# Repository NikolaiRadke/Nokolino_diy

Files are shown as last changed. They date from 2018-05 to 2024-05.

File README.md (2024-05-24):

Nokolino
  
The ATtiny-based litte brother of Noko. This is the Repository for the **diy - Do It Yourself** version. Tiny and cute. And everyone is invited to **contribute**. Nokolino is for everyone. Are you looking for the new PCB version? Look here: [Nokolino_pcb](https://github.com/NikolaiRadke/Nokolino_pcb), or are you an owner of a kit? Look [here](http://github.com/NikolaiRadke/Nokolino).  
  
What's new? See the [newsblog](https://github.com/NikolaiRadke/Nokolino_diy/tree/master/NEWS.md).   
  
Three Nokolinos
  
Like his big brother **Noko**, the little Nokolino delights it's surroundings with cheeky comments. But unlike Noko he is more obstinate - no radio, no display, no frills. Instead of an Arduino he has a small **ATtiny** microcontroller, only an on-off switch and a big button. But he is small, can stay active for days and is, in contrast to his big brother, very easy to build.  
  
Another useful application option would be to use the hardware without the monster suit as a **music box** in an old used doll to bring it back to modern days, maybe with other sounds or songs.  

What does he to - technically? Whenever you press his button, he will laugh. And when he's just turned on, he says something random randomly every statistically 10 minutes. That's ist. Quiet a lot for a stuffed monster!  
  
**Nokolino** stands for **No**ra and Ni**ko**s monster - the appendix **lino** describes the small version.  
  
### Notes for non-German Nokolino makers  
  
Right now, the building wiki, the voice set and the manual are in German. I'll try to translate the wiki and the manual on day. Until then, feel free to ask me for translation, if you need help. **Contribute!** I need an English voice set and English text files. In addition, any other language is welcome, Nokolino is to be cosmopolitan!
  
### Prerequisites
  
Nokolino needs Arduino IDE 1.6.6 or newer (https://www.arduino.cc/en/Main/Software). Copy the folder `Nokolino_diy/src/Nokolino/` into your sketch folder and install ATtiny support. See [how to compile](https://github.com/NikolaiRadke/Nokolino_diy/tree/master/howto_compile) for further instructions. 
  
### Content

```
Nokolino_diy/
├── howto_compile/
|   Manual how compile the sketches in your Arduino IDE and precompiled sketched  
|   └── precompiled/
|       Precompiled hex files
|       ├── ATtiny45/
|       |   Version for the ATtiny45.
|       └── ATtiny85/
|           Version for the ATtiny85.
|
├── linux_uploader/
|   Tool for uploading MP3-files to the JQ6500.
|
├── manual/
|   Nokolino manual in PDF format and a template for a packaging design.
|   └── scribus/
|       Source documents for Scribus with all illustrations and fonts.
|
├── mp3/
|   Voice set for Nokolino/Nokolina in German. English needed? Contribute!
|   ├── female/
|   |   Female voice for Nokolina.
|   |   ├── mp3_16MBit/
|   |   |   Voice set for the 2MB-JQ6500.
|   |   └── mp3_32MBit/
|   |       Enhanced voice set for the 4MB-JQ6500. 
|   └── male/
|       Male voice for Nokolino.
|       ├── mp3_8MBit/
|       |   Low qualitiy files for the 1MB-JQ6500.
|       ├── mp3_16MBit/
|       |   Voice set for the 2MB-JQ6500.
|       └── mp3_32MBit/
|           Enhanched voice set for the 4MB-JQ6500.  
|
├── schematics/
|   The schematics for the Nokolino parts, the Nokolino sewing pattern and shopping list.
|   └── geda/
|       Source documents for gEDA.
|
└── src/
    ATtiny sketch
    └── Nokolino/
        One file, no libraries, no frills. Just Nokolino. 
```
### Let's get started!

Interested in Nokolino? Great! Let's start here: [German wiki](https://github.com/NikolaiRadke/Nokolino_diy/wiki).  
English wiki will follow. One day...

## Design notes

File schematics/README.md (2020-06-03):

# Schematics

### Technical schematics
* **Nokolino.png**:  
NOKOlino's main schematic. It was written with [gEDA](http://www.geda-project.org/).  
* **Nokolino_phototransistor.png**:  
Optional light sensor extension schematic.  

### Other manuals

* **Nokolino_Pattern.pdf**:
NOKOs sewing pattern. 
* **Nokolino_Einkaufsliste.pdf**:
Shopping list in German.

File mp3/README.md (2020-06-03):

# Voice set for Nokolino - German

There are five sets: Three **male** sets, one for the 16MBit = **2MByte** variant of the JQ6500, and one for the 8MBit = **1MByte** variant in lower quality and a 32MBit **4 MByte** variant with more sound files, for newer 32MBit-JQ6500 modules. The fourth set is a 32MBit **4 MByte** **female** variant, brand new for *Nokolina* and the last set ist the 16MBit **2 MByte** variant.    
  
Copy these mp3s on the JQ6500 module. Strictly observe the sequence!
021.mp3 must be copied as the 21st file. See the [Wiki](https://github.com/NikolaiRadke/Nokolino_diy/wiki/MP3s-aufspielen) for more detailed instructions.  
  
**Windows** users can use the (chinese) interface. See this [instructions](http://sparks.gogo.co.nz/jq6500/index.html), written by James Sleeman. **Linux** and **Mac** users should try the [uploading tool](https://github.com/NikolaiRadke/Nokolino_diy/tree/master/linux_uploader), written by Max Reinhard.  
    
 **16MBit:**  
  
| Number  | Assignment |
| ---|---:|
| 001-030 | Response to belly button |
| 031-079 | Time based events |
| 080 | BEEP battery warning |
  
 **32MBit:**  
  
| Number  | Assignment |
| ---|---:|
| 001-040 | Response to belly button |
| 041-163 | Time based events |
| 164 | BEEP battery warning |
  
The male voice has been spoken by my fellow actor [Carsten Caniglia](https://filmmakers.de/carsten-caniglia). Why? 
He has done a great job - moreover I don't want to listen to my own voice every day, especially when development takes more than a year! (Ian said I sound really weird in real life. Thanks, mate.). The female voice was spoken by my fellow actress [Norma Anthes](http://norma-anthes.de), thank you, lady!    

### Your own voice set  
  
You want to use your own files? No problem. Look into the sketch **Nokolino.ino**, set the definition **Set_own** and change the lines  
``` #define Button_event  0 ```  for the last voice file when the button is pressed and  
``` #define Time_event   0``` for the last voice file for the time based events.  
The *beep* for the battery warning should be the last file.  
  
Keep in your mind, that the device ist limited to **4Mbyte - 256kb**, **2MByte - 256kb** or **1MByte - 256kb**!

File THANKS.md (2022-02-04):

# Thanks

These people helped me bringing life to Nokolino:  
  
- **Hans Radke** - (my dad) hardware construction and a lot of soldering.
- **Regina Radke** - (my mom) monster suit hints.  
- **Nora Linder** - creating and sewing the monster suit and spellchecking.
- **Carsten Caniglia** - the male voice of Nokolino. Look at his [Homepage](https://neidig.org/carsten-caniglia/). 
- **Norma Anthes** - the female voice of Nokolina. Look at her [Homepage](http://norma-anthes.de).  
- **Helga Hansen** - from the Make Magazin for promoting Nokolino.  
- **Elisabeth Seidl** - Media design.  
  
Active supporters:  

- **"Brickhub"** - bugfixes.  
- **Horst Friedrich** - the phototransistor idea.  
- **Daniel Bachfeld** - the QI wireless charging idea.  
- **Thomas Stolt** - bugfixes and Nokolino_pcb.  
- **"Nickneck"** - translating the JQ6500 uploader.  
- **Reinhard Max** - for the upload and rescue tool.  
  
Used ressources:  

- **Arduino board and IDE** - [www.arduino.cc](http://www.arduino.cc)  
- **ATtiny core** - [David A. Mellis](https://github.com/damellis)  
- **JQ6500 uploader** - [Reinhard Max](http://chiselapp.com/user/rmax/repository/jq6500)  
- **Suit inspiration - Ninni** - [RevoluzZa Blog](http://blog.revoluzzza.com/2009/02/25/tutorial-hopw-to-sew-a-revoluzzzionary-monster-wie-man-ein-revoluzzzionares-monster-naht/)  
- **VCC measuring** - [Tim on mikrocontroller.net](https://www.mikrocontroller.net/topic/315667)

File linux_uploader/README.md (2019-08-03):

# Uploading files on the JQ6500 with Linux

It is quite easy with this command line tool, written by [Reinhard Max](https://chiselapp.com/user/rmax/repository/jq6500).  I added a precompiled version (64 Bit). It is free, but it is also *beerware*... ;-)  

1. Check, if ``` ./jq6500 ``` is running.  
2. If not, compile it by yourself, just by typing ``` make ```. 
3. Try again.
4. Connect your JQ6500 module to your system with a micro USB cable. 
5. Test your device by typing  ``` ./jq6500 -S ```. The tool will tell you the detected flash size.  
6. 32 MBit modules: Upload your files by typing ``` ./jq6500 -W ../mp3/male/mp3_32MBit/* ```(32 MBit male voice)  or ``` ./jq6500 -W ../mp3/female/mp3_32MBit/* ``` (32 MBit female voice).  
7. 16 MBit modules: Upload your files by typing ``` ./jq6500 -W ../mp3/male/mp3_16_MBit/* ```(16 MBit male voice)  or ``` ./jq6500 -W ../mp3/female/mp3_16MBit/* ``` (16 MBit female voice). 

If your MP3 files are in another directory, modify the last argument.  

## Repairing a JQ6500 without Windows software
  
Strangely, some modules come without the integrated Windows software. If you have a friend in need without Linux, the tool can fix the module.

1. Like above, check if the tool is running correctly.  
2. Connect your JQ6500 module to your system with a micro USB cable.  
3. Just type ``` ./jq6500 -X ```. 

That's it. You can now use your module with Windows.  
  
## Repairing a JQ6500 without Windows software without Linux
  
If you are a Windows user see my [JQ6500-rescue-tool](https://github.com/NikolaiRadke/JQ6500-rescue-tool) repository. There you find a quite simple way to fix your module.

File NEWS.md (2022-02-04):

# Newsblog

# 2020
  
* **10.07.2020** Tested new IDE 1.8.13. Works good.  
* **04.06.2020** New release **V1.2-030819**.  
* **03.06.2020** The repository got a small rework.  
* **09.03.2020** Tested IDE 1.8.12. Yeah, it's working, too.  
* **13.02.2020** Tested IDE 1.8.11. Again, it's working.  
  
# 2019  
  
* **26.09.2019** Tested IDE 1.8.10. Still working.  
* **27.08.2019** New linux upload and repair tool. The make command now works with Debian/Ubuntu/Mint.  
* **05.08.2019** New release **V1.1-030819**.  
* **03.08.2019** Firmware **2.1-030819**: With some small hardware additions Nokolino can get a new voice set via USB!  
* **14.04.2019** Testet IDE 1.8.9. with no problems found.  
* **15.01.2019** Firmware **2.0-150119**: Reworked volume control. Some modules have issues after sleep mode.  
* **15.01.2019** Testet IDE 1.8.8. Works well.  

## 2018  

* **19.10.2018** New Linux upload tool. You can upload an english interface by typing ./jq6500 -X   
* **26.09.2018** See Nokolino and me at Wissensnacht Ruhr Gelsenkirchen: 28.08.2018.  
* **25.09.2018** Firmware **2.0-250918**: Optional complaining when button is pressed while it is dark.
* **22.09.2018** Firmware **2.0-220918**:
  * Optional startup beep.  
  * Optional phototransistor feature.  
  * Improved volume handling, some modules need more startup time.  
* **03.09.2018** See Nokolino an me at the Maker Faire Hannover: 15.09.-16.09. HCC Hannover.  
* **29.06.2018** Firmware **1.0-290618**: Improved power saving when battery is low.  
* **16.06.2018** Updated the upload tool.  
* **24.05.2018** Firmware **1.0-240518**: New 16MBit voiceset support.  
* **23.05.2018** Better data compression for 16MBit voiceset. You get 10 more files!  
* **15.05.2018** Updated the upload tool for the JQ6500 mp3 module. Note that it now needs the **-W** parameter to write files.  
* **14.05.2018** See Noko, Nokolino and me at the Maker Faire Berlin: 25.10.2018-28.10.2018, FEZ!  
* **12.05.2018** The new [Nokolino_pcb repository](https://github.com/NikolaiRadke/Nokolino_pcb) ist finished. I will still provide support for the old version. Promised.  
* **11.05.2018** The new female voice set for Nokolina is finished.  
* **04.04.2018** My hoster was offline for more than two weeks. I moved to a new one. The graphics in the GitHub will be back soon. What a waste of time...  
* **16.03.2018** Finished a JQ6500 rescue tool! See [my new repository](https://github.com/NikolaiRadke/JQ6500-rescue-tool).  
* **12.03.2018** New Firmware **1.0-120318**: Nokolino is now talking constantly while button is pressed.  
* **08.03.2018** Fixed flash tool for 32MBit MP3 modules.  
* **22.03.2018** Nokolino appears in the german [Make Magazin](https://www.heise.de/select/make/2018/1/1519698748803933)!  
* **27.01.2018** New firmware **1.0-270118**:  
Enhancement: Using EEPROM.length() makes ATtiny selection obsolete.  
* **26.01.2018** New firmware **1.0-260118**:  
Bugfix: New voice set selection compiles without errors now.  
Enhancement: Easy PCD/Breadboard switching.  
* **13.01.2018** Firmware **1.0-130118** and the enhanced voice set files for the 32MBit-JQ6500 variant added.  
* **11.01.2018** **Hardware bug found**: The speaker is connected to *pin 16 and pin 15*, not *pin 16 and pin 14*.   
* **10.01.2018** Alas, another bug found. New firmware **1.0-100118**:
Bugfix: Custom voice set with own events is now working correctly.  
* **09.01.2018** New firmware **1.0-090118**:  
Bugfix: EEPROM seed cyle now runs without initial settings.  
* **08.01.2018** Nokolino appears on [Heise Newsticker](https://www.heise.de/make/meldung/Nokolino-die-Miniaturausgabe-von-MP3-Monster-Noko-3935030.html)!  
* **05.01.2018** New firmware **1.0-050118**:  
Bugfix: Last time event was unused.  
Enhancement: Easier optional voice set replacement.
* **04.01.2018** Bugfixing day.  
* **03.01.2018** Finished the Wiki - Nokolino is ready for the world with release **V1.0-030118**.   
* **02.01.2018** Finished the GitHub. Now the Wiki will be completed.  
* **01.01.2018** Happy new year! I finished the sewing pattern this (tired) day.  
  
## 2017
* **31.12.2017** Created this file. Nokolino is ready to release! Wait! Not now, it is party time :-)  
The hardware is finished and the firmware **1.0-250517** is working great.

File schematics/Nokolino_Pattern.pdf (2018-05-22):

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

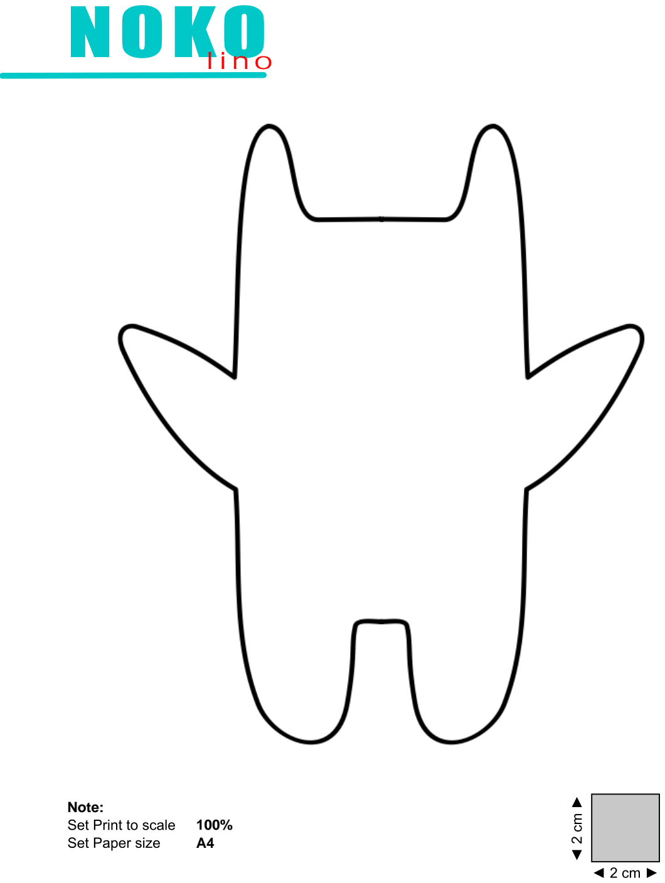
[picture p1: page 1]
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

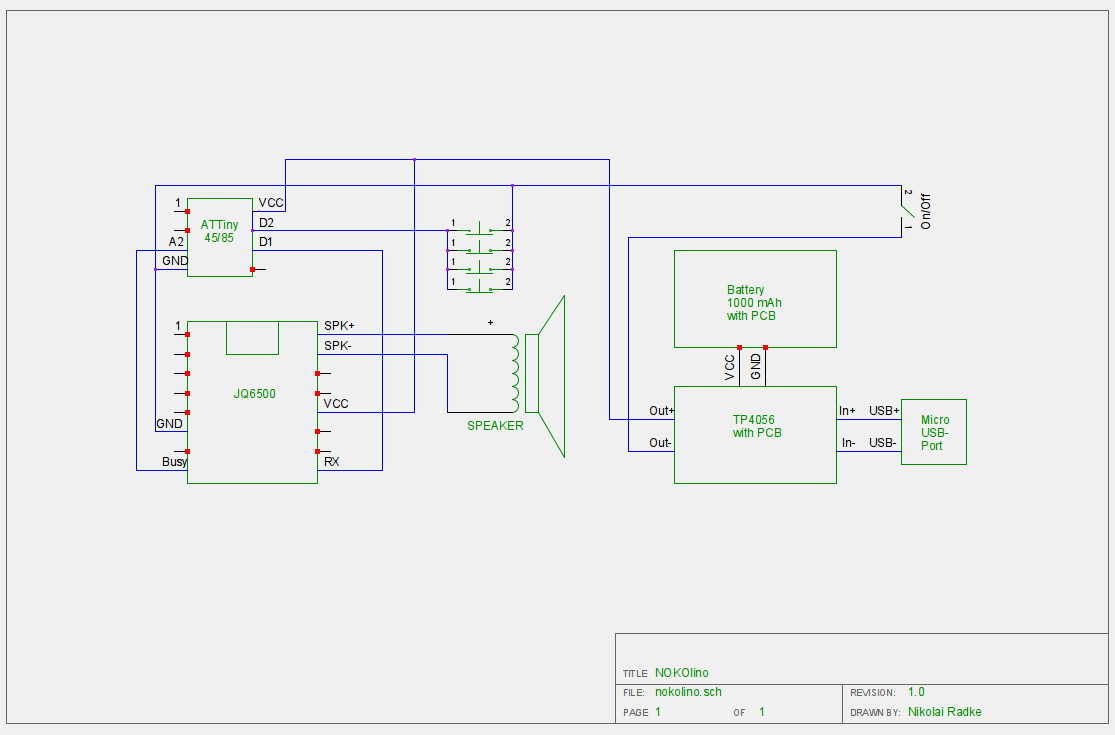
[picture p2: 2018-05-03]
schematics/Nokolino.png

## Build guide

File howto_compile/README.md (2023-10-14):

# Compiling instructions for Nokolino

In order to flash your ATtiny with the Nokolino-sketch, you need the **Arduino-IDE** (1.6.6 or higher), with installed **ATtiny-support** and an **Arduino** connected to your microcontroller.

### Preparing the IDE  
 
1. Open ``` File > Preferences ```.  
2. Find the field ``` Additional Boards Manager URLs ```.  
3. Enter ``` https://raw.githubusercontent.com/damellis/attiny/ide-1.6.x-boards-manager/package_damellis_attiny_index.json ```.  
4. Press ``` OK ```.  
5. Open ``` Tools > Board > Boards Manager ```.  
6. Select ``` attiny by David A. Mellis ```.  
7. Press ``` Install ```.

### Peparing your Arduino  

1. Connect your Arduino to your system.  
2. Open ``` File > Examples > ArduinoISP > ArduinoISP ```.  
3. Upload the sketch.

### Connecting your ATtiny with the Arduino  

1. Disconnect your Arduino.
2. Connect your ATtiny as seen below.
3. Add the 10uF capacitor.      
  
ATTINY-ARDUINO  
  
### Burning an Attiny bootloader  

1. Connect your Arduino to your system again.  
2. Select ``` Tools > Programmer > Arduino as ISP ```.  
3. Select ``` Tools > Board > ATtiny25/45/85 ```.  
4. Select ``` Tools > Processor > ATtiny85 ``` or ``` Tools > Processor > ATtiny45 ```.  
5. Select ``` Tools > Clock > 8 MHz (internal) ```.  
6. Start burning process with ``` Tools > Burn Bootloader ```.  

Now you can flash your ATtiny with any sketch you want! But this time, we focus on Nokolino.  

### Configuring Nokolino.ino

1. Set the avarage talking interval in line 31 (10 for 10 minutes is preset).  
. Set the volume in line 32. 25 is recommended for Nokolino, 22 for Nokolina.  
3. Are you building Nokolino on a breadboard? Set line 35.  
4. Select your voice set in line 38, 39 or 40  
5. If you don't want any battery warnings, comment out line 64.  
6. If you want Nokolino to be quiet on startup, comment out line 66.  
7. Check line 65 if you are using the optional light sensor.  

### Flashing Nokolino firmware
  
1. Open sketch **Nokolino.ino**.  
2. Upload the sketch.  
3. DONE.  

Now you can remove the microcontroller. You should keep the wiring alive to easly make some changes in the firmware.

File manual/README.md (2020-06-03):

# Manual for Nokolino
This folder contains the 6 page manual as a PDF, written in German. 
  
It has been written with [Scribus](http://www.scribus.net). The source files, fonts and illustrations are
in the folder [/scribus](https://github.com/NikolaiRadke/Nokolino_diy/tree/master/manual/scribus), so you can change 
the manual as you wish or translate it in any language. Please fork this repository or send a copy.

The other "2in1"-file is intended for printing a smaller manual with two pages on one. Choose duplex, 2 Pages on one and short edge.

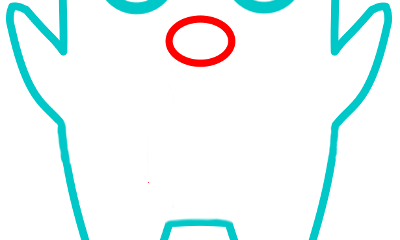
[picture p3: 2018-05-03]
manual/scribus/nokolino_bauch.png

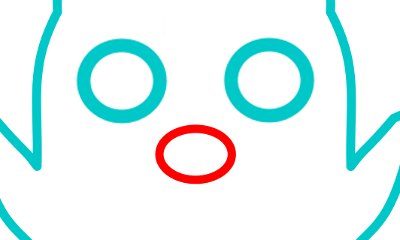
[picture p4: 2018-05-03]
manual/scribus/nokolino_lautsprecher.png

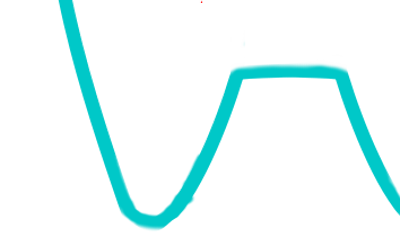
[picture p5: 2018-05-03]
manual/scribus/nokolino_usb.png

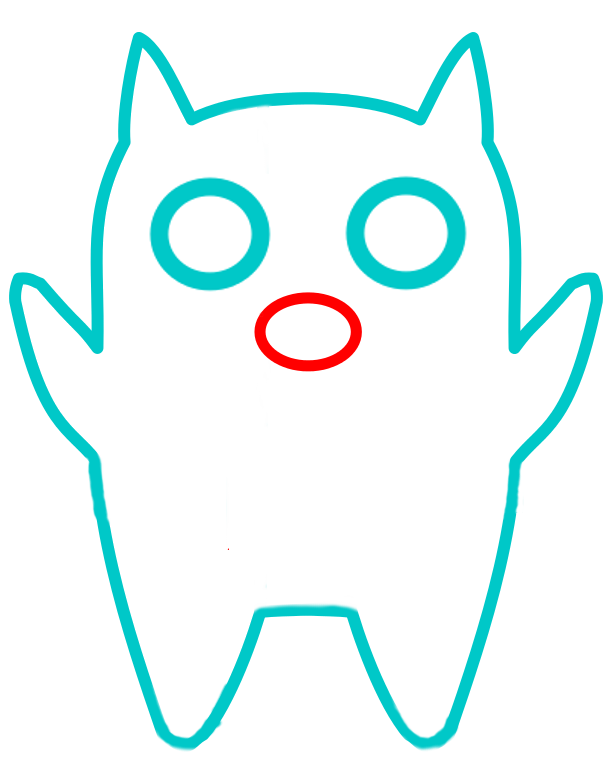
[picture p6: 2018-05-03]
manual/scribus/nokolino.png

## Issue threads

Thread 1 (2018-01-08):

Was macht der genau?

supertobi, 2018-01-08:
Mir fehlt eine Beschreibung, was das Monster denn jetzt macht.
Wenn ich den Quellcode richtig verstehe wird ca. alle 10 Minuten eine zufällige Datei abgespielt und eine spezielle beim drücken des Button. Ist das richtig so?

NikolaiRadke, 2018-01-08:
Genau.
Und wenn der Akku zuneige geht, sagt er "Piep". Ansonsten frisst er Strom :-)
Vielleicht sollte ich das im Wiki etwas deutlicher machen.

supertobi, 2018-01-08:
Ja, bitte.

NikolaiRadke, 2018-01-08:
Ist erledigt :-)

LG

Closed 2018-01-08.

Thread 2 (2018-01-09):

Wo wird der EEPROM initialisiert?

Brickhub, 2018-01-09:
Noch sind meine Teile zum Nachbauen nicht angekommen - da habe ich etwas Zeit mir den Code anzuschauen und eventuell etwas daraus zu lernen - wie z.B. die Verwendung des EEPROMs (Den habe ich bisher noch nie benutzt).
Wenn ich den Code richtig verstanden habe, sollte doch zu Anfang auf der Adresse 0 eine 2 stehen und auf Adresse 2 eine 0. Wo wird das gesetzt?
Wenn der EEPROM initial auf 0 gesetzt wird (Vermutung) dann fehlen doch folgende Zeilen:

`// Randomize number generator`
`  address=eeprom_read_word(0);       // Read EEPROM address`
**`  if (address == 0)`**
**`  {`**
**`    address = 2;`**
**`    eeprom_write_word(0,2);`**
**`  }`**
`  seed=eeprom_read_word(address);    // Read seed`

NikolaiRadke, 2018-01-09:
Danke für den Hinweis.
Du hast völlig recht, des EEPROM wurde vorher von mir mit einem Hilfsprogramm initialisiert, das habe ich hier vergessen. Nun überlege ich, ob ich Deinen Code einfüge und auf das Tool verzichte. Allerdings gibt es da ein Problem. Zunächst ist das EEPROM von ATMEL-Chip werkseitig mit 255 beschrieben. Ich könne also nach 65536 abfragen. Das geht aber nur, wenn das EEPROM "jungfäulich" ist.

Was meinst Du?

Brickhub, 2018-01-09:
Im Prinzip ist es egal bei welcher Adresse man startet, sie sollte halt nur >= 2 sein und darf nicht max_address übersteigen. Mann kann dann auch mit einem alten Datenmüll starten. Ich würde das ganze dann so vorschlagen:

`// Randomize number generator`
`  address=eeprom_read_word(0);       // Read EEPROM address`
`  if ((address < 2) || (address > max_address)) `
`  {`
`    // Hier kommt man nur beim ersten Aufruf hin, wenn die initiale EPROM-Füllung unpassend ist`
`    address = 2 `
`    eeprom_write_word(0,address);`
`    eeprom_write_word(address,0);  // Optional, man kann auch mit dem zufälligen Wert im EPROM starten`
`  }`
`  seed=eeprom_read_word(address);    // Read seed`
`  if (seed>900)                      // After 900 write-cyles move to another address`
`  {                                  // to keep the EEPROM alive`
`    seed = 0; `
`    (address>max_address)? address=2:address+=2;`
`    eeprom_write_word(0, address);`
`  }`
`  randomSeed(seed);`
`  seed++;`
`  eeprom_write_word(address,seed);   // Save new seed for next startup`

NikolaiRadke, 2018-01-09:
Dabei habe ich auch gleich max_address angepasst: Der Attiny85 hat 512 Bytes und der ATtiny45 256 Bytes. Bin von der Hälfte ausgegangen.

Brickhub, 2018-01-09:
> Die zweite (address>max_address)-Abfrage ist dann überflüssig
Hmm, ja, das wollte ich zuerst auch vorschlagen. Aber address wird nacht der Erhöhung und vor der nächsten Überprüfung noch einmal verwendet. Es ist unkritisch, wenn max_address+2 immernoch eine gültiege Adresse ist. Das darf man dann nicht vergessen, wenn man mal max_address an andere MCUs anpassen möchte. Deshalb würde ich hier die Abfrage lieber doch beibehalten.
Oder man verschiebt den Block mit seed-Erhöhung und Speicherung vor den seed>900 Block (in den dann aber auch ein ` eeprom_write_word(address,0); ` eingefügt werden muss, was im Grunde auch wieder eine Code-Verdoppelung bedeuten würde.

Brickhub, 2018-01-09:
Oder noch einfacher: Man prüft auf
`if ((address < 2) || (address > max_address - 3)) `
Dann darf max_address der größten Adresse entsprechen, was die Definition erklärlicher machen würde.
Beim Arduino gibt es da `EEPROM.length()` in der `<EEPROM.h>` - geht das auch bei den ATtinys? Dann könnte man die Definition komplett einsparen.

NikolaiRadke, 2018-01-09:
Das ist natürlich die eleganteste Lösung!
Der Compiler jedenfalls meckert nicht bei EEPROM.length():

´´´
// Randomize number generator
  address=eeprom_read_word(0);       // Read EEPROM address
  if ((address<2) || (address>(EEPROM.length()-3)))     
  {                                  // Initialize EEPROM and size for first use or after end of cycle
    address = 2;                     // Starting address
    eeprom_write_word(0,address);    // Write starting address
    eeprom_write_word(address,0);    // Write seed 0
  }
  seed=eeprom_read_word(address);    // Read seed
  if (seed>900)                      // After 900 write-cyles move to another address
  {                                  // to keep the EEPROM alive
    seed=0;
    address+=2;
    eeprom_write_word(0,address);
  }
  randomSeed(seed);                  // Randomize
  seed++;                            // New seed
  eeprom_write_word(address,seed);   // Save new seed for next startup
´´´
Danke für Deine Hilfe!

Brickhub, 2018-01-10:
Ja, so sieht das super aus.

Closed 2018-01-10.

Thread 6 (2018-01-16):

Leiterplatte

NikolaiRadke, 2018-01-16:
Der Entwurf ist natürlich schick, aber wäre dann noch Platz oberhalb des TP für den Lautsprecher? Unten kommt nicht in Frage, das klingt grauenhaft. Wenn ja, hätte es den Vorteil, dass der Akku unten auch eine andere Bauweise haben könnte.

Wäre es möglich, das MP3-Modul um 180 Grad zu drehen? Sollte das Innenleben als Spielwerk verwendet werden, kann so leicht ein neues Lied aufgespielt werden.

Vielen Dank schon mal für die Mühe!

LG,
Nikolai

Crayfish68, 2018-01-17:
Hallo Nikolai

Jawoll. Ich habe die Leiterplatte auf 5cm x 5cm gebracht, passt mal wieder alles gerade so drauf :)
Auf diese Art können wir dann beim Hersteller auf einer Leiterplatte von 10cm x 10cm jeweils 4 unterbringen. Wenn wir davon dann 10 bestellen, haben wir 40 Boards. Sollte erst einmal reichen.* Preislich wären wir dann irgendwo bei 1,20€ für das Board ([16.42 + 29.91 shipping] /40 = 1,16€, wenn kein Zoll dazu kommt).

Ich habe wieder USB Pins für das MP3 Modul angelegt, die werden dann zum USB Anschluss geroutet.

Ich habe alle Module so weit wie möglich an den Rand geschoben, um möglichst viel Platz für den Lautsprecher zu schaffen. Der Lautsprecher ragt dann nur teilweise (6,7mm) über das MP3 Modul, was ja relativ flach ist.
Wenn du Platz für den ganzen Lautsprecher haben möchtest, dann müsste das Board größer gemacht werden (z.B. 5cm x 6cm), auch kein Problem. Dann wird es vielleicht etwas teurer ... nagut, sind dann vielleicht 2€, auch kein Drama.
Kannst du noch mal BxHxL von deinem Akku sagen? Vielleicht macht es Sinn, Lautsprecher und Akku nebeneinander auf eine Platine zu bringen und dann diese Platine darunter? Dann verringert sich die Gesamthöhe noch einmal deutlich.

vG
Crayfish

*es wurde schon für den nächsten Kindergeburtstag dieses Projekt angefragt - wenn das alles so klappt, würde ich dann ca. 10 nehmen - dauert aber noch, September...

Crayfish68, 2018-01-18:
Dank "Frederike" geht es schon hier weiter:

Die Idee war jetzt, genug Platz für den Lautsprecher zu schaffen. Er bekommt auch direkt die passenden Befestigungslöcher, so kann er auf der Hauptplatine mit M2 Schrauben befestigt werden (strahlt natürlich nach oben), bekommt dort auch gleich seine zwei Pins, so das er nicht über irgendwelche Stecker angeschlossen werden muss.
Damit das passt, musste ich die Leiterplatte 5cm x 6cm machen. Preislich macht das nur minimal Unterschied.

Als Stecker müssen wir gewinkelte nehmen:  gerade Stecker stünden ja hoch und passen daher nicht. Ich habe die Footprints mal entsprechend angepasst und auch die 3D Models dafür gefunden.

So sieht es jetzt aus in der 5x6cm Version:
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
Hier mal ein 3D Eindruck:
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

Alternativ hätte ich auch eine 5x5cm Variante anzubieten:
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
da hatte ich jetzt noch nicht die gewinkelten Stecker, aber es geht ja nur darum zu zeigen, wie der Lautsprecher über das TP Modul drüber ragen würde. Der Lautsprecher müsste dann an die obere Platte angebracht werden.

Ist beides machbar. Ich persönlich finde die 5x6cm Variante schicker, aber vielleicht übersehe ich ja irgendwas.

vG
Crayfish

NikolaiRadke, 2018-01-19:
Frederike und NOKOlino sind eindeutig Freunde :-)

Der Lautsprecher muss unbedingt an die obere Platte angebracht werden, um einen akustischen Kurzschluss zu vermeiden. Wäre er unten, klänge es schrecklich.

Auch frage ich mich, ob wir Stecker brauchen. Das Crimpen ist aufwändiger, als diese paar Kabel anzulöten, oder? Dann wäre auch Platz für einen (gewinkelten?) USB-Stecker für das MP3-Modul, um D+ und D- herausführen zu können.

Wenn der Preisunterschied so minimal ist, dann ziehe ich 5x6cm vor, da es so auch mehr Auswahlmöglichkeiten für den Akku gibt.

LG
Nikolai

Crayfish68, 2018-01-19:
Das mit dem akustischen Kurzschluss wusste ich natürlich sofort - wollte nur testen, ob du auch aufpasst!

;)

Ja, Stecker ist schon irgendwie total overkill. Kann es sein, dass NOKOlino ein heimlicher Streber ist!?
Nunja, so haben alle alle (!?) Optionen, können entweder Stecker kaufen, oder auch nicht. Wenn sonst nichts dagegen spricht, lasse ich sie so.

Dann nehme ich die Befestigungs-Löcher aus dem Lautsprecherfootprint wieder raus, lasse aber die Lötaugen drin, dann kann er da direkt angeschlossen werden.
Ich schiebe auch noch das MP3 Modul so weit runter, das möglichst viel Platz für einen USB Stecker da ist. Vielleicht magst du das dann mal ausdrucken, die Module (MP3 Modul, ich habe noch keins), und die Taster rauflegen und gucken, ob wir die Größe eines fertig konfektionierten USB Steckers da nicht unterschätzen? Und ob die Richtung stimmt?! Ich hatte an meine "Selbstlötstecker" gedacht, die passen da locker hin, aber normale, speziell die gewinkelten, sind im Vergleich dazu 'riesig'. Zumindest kommt es mir so vor.
Ich gucke mal, ob ich es in ein PDF drucken kann und werde es dir dann schicken, zum ausrucken.

Noch eine Frage: was hast du eigentlich als Kappen für die Taster in Richtung obere Platine genommen? Gab es diese Kappen zu den Tastern dazu? Ich habe Schwierigkeiten welche zu finden, die Online Kataloge sind Datengräber :/

NikolaiRadke, 2018-01-21:
Die Kappen nennen sich "Tastkappen". Sowas hier z.B.:
https://www.conrad.de/de/tastkappe-gelb-diptronics-ktsc-61y-1-st-705361.html

PDF wäre praktisch, dann probiere ich das mal aus.

Crayfish68, 2018-01-21:
PDF kommt mit dem nächsten Pull, ein Request müsste bei dir noch liegen, oder?

Obere Leiterplatte kommt auch demnächst...

vG
Crayfish

NikolaiRadke, 2018-01-21:
Ne, den Request hast Du Dir ins eigene Repository gesetzt :-)

NikolaiRadke, 2018-01-21:
Sehr schick, die obere Platte
 Aber ich glaube, das ist vielleicht zu instabil, da ja genau dort mit den (brutalen!Kinder-) Händen gedrückt wird, oder?

Crayfish68, 2018-01-22:
Mh, da magst du recht haben. Im PCB Editor sieht das immer alles super aus.
Mach mal n Vorschlag! Vielleicht mit Löchern? Oder die Schlitze 1mm und die Stege auch 1mm? 2mm?
Ich habe schon erfolglos nach Ideen bei Google gesucht - stehe grad irgendwie noch auf dem Schlauch. Bräuchte mal wieder eine kreative Phase...

vG
Crayfish

NikolaiRadke, 2018-01-23:
Ich glaube, Du bist da einfach zu akribisch :-)
Bei mir sieht das so aus:
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

NikolaiRadke, 2018-01-27:
Ich denke, ein paar Löcher reichen locker, ggf. auch streifen mit einigen Millimeter Stärke und Abstand.

Crayfish68, 2018-01-27:
Naja, ich hab es gerne immer so schick es geht ;)

Neuer Versuch: Breite der Schlitze ist jetzt 2,5mm, dazwischen jeweils 2mm Steg, mit nochmal 4 Querstegen. Sollte in jedem Fall stabiler sein, als die Lochrasterplatte. Da ist ja auch noch Kupfer oben und unten drauf.

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

PDF als Größenabgleichsausdruckdokument hängt auch an.

vG
Crayfish
[Ausgabe.pdf](https://github.com/NikolaiRadke/NOKOlino/files/1670513/Ausgabe.pdf)

NikolaiRadke, 2018-01-28:
Habs getestet, passt super. Jetzt bitte noch das Logo tauschen und mir erklären, wie zwei Platinen in eine Bestellung kommen, dann geht der Auftrag nach Fernost :-)

Crayfish68, 2018-01-28:
Die Logos sollten stimmen.

Ich habe hier noch ein kleines Problem: der PCB Hersteller nimmt keine Orders an, wenn kein Drill File dabei ist. Ich habe jetzt einfach "Fake" Lötpunkte gesetzt. Ich habe mir gedacht, ich setze sie genau mittig dort, wo unten die Taster sind. Dann kann man es vielleicht besser ausrichten, oder vielleicht mit einem Schräubchen die Taster fixieren (wenn der Kleber nicht hält), oder aufbohren und dann die Taster reinkleben, oder ... oder ..., ...

Spricht was dagegen?
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

Crayfish68, 2018-01-28:
Also, passend zu dem "jetzt können wir ordern" hat easyeda natürlich ihre Webseite geändert und jetzt (wie allerdings bereits angedroht) zu jlcpcb.com umgeschaltet. Außerdem feiern sie Chinese New Year vom 10.2 bis 23.2. (!!), es könnte sich also alles ein bischen verzögern.
Das sollten allerdings keine grundsätzliche Hindernisse sein. Also, ich würde denken (nachdem du gepullt hast) gehst du folgendermaßen vor:

1. auf jlcpcb.com einen Account anlegen
2. die NOKOlino/schematics/kicad/GERBERS/NOKOlino_Gerbers.zip hochladen
 a.  Breite/Länge sollte sich automatisch auf 60/50 stellen
 b. Bei "Panel By JLCPCB" auf "Yes" und dann "2" und "2" in die Boxen (dann bekommen wir 10 boards, auf denen jeweils 4 break away boards sind, so verstehe ich das jedenfalls)
 c. Save to Cart
3. dasselbe dann noch einmal mit NOKOlino/schematics/kicad_top_pcb/GERBERS/kicad_top_pcb.zip
4. dann solltest du beide im Cart haben und zur Kasse gehen, dort wird dann Shipping draufgelegt.

Order Alternative 1:
- Preis für 4 x 10 = 40 PCBs ist $27,81
- Shipping ist $26,68
- macht zusammen $82,30.
- geteilt durch 40, dann landen wir pro Satz (eine obere, eine untere PCB) bei $2,05.

Order Alternative 2:
- Preis für 10 x 1 = 10 PCBs ist $2
- Shipping ist $22,08
- macht zusammen $26,08
- geteilt durch 10, dann landen wir pro Satz (eine obere, eine untere PCB) bei $2,60.

Wenn noch irgendwas nicht stimmt mit den Leiterplatten, dann hast du bei der Alternative 1 einen ziemlich großen haufen Müll :/

Vielleicht gibt es noch andere Kombinationen, die dass noch günstiger macht. Ich habe jetzt nichts anderes mehr durchprobiert.

Augen zu und durch! Hoffentlich klappt diesmal alles auf Anhieb!!

vG
Crayfish
PS: der GERBER Viewer auf deren Webseite zeit die Schrift auf der Rückseite des Boards spiegelverkehrt an. Bei mir in KiCad sieht es allerdings richtig aus.

NikolaiRadke, 2018-01-29:
Uiuiuiui - ich habe mich für Alternative 2 entschieden, weil dann keine Steuern anfallen. Hauptsache, die Platinen kommen vor dem Neujahr, da geht echt wochenlang nix.

Komisch, dass mir trotz DHL Express nur 9$ berechnet wurden...

NikolaiRadke, 2018-02-03:
Die Platinen sind heute in Berlin angekommen. Montag sind sie da :-)

Crayfish68, 2018-02-03:
Tschakka!! Ich liebe parallele Projekte :/

Bin eh bis nächste Woche in Ö, lass dir also Zeit!

Von meinem iPhone gesendet

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

NikolaiRadke, 2018-02-05:
Schade, die Platinen sind leider unbrauchbar. Die Taster sind falsch beschaltet, sie müssten um 90 Grad gedreht werden. Auch ein zurechtbiegen der Beine wird nicht helfen, da sie ja exakt eben auf der Platine sitzen müssen, um die obere Platine zu halten.

Naja, 9€ Lehrgeld und ein paar verplemperte Bauteile.

Crayfish68, 2018-02-05:
Sch.......!!!!

NikolaiRadke, 2018-02-05:
Ja nu - keine 15€ verballert. Schade ist es höchstens um die Zeit, aber ich habe es auch nicht wirklich eilig :-)

Crayfish68, 2018-02-05:
Schick mir trotzdem mal 2 bitte, dann guck ich mir das an. Ärgerlich :(

NikolaiRadke, 2018-02-05:
Klar, mach ich gern.
Auf Anhieb ist doch nie was fehlerfrei. Nächste Version wird super :-)

Crayfish68, 2018-02-12:
Kannst du mir auch noch bitte die genaue Bezeichnung (am besten einen Link) zu den Tastern geben, die du verwendest? Im Idealfall bräuchte ich das Datenblatt. Welche Höhe an Tastern verwendest du?

NikolaiRadke, 2018-03-05:
Fazit:

Closed 2018-03-05.

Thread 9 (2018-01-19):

Akku / Batterie

Crayfish68, 2018-01-19:
Vielleicht noch ein Issue zum Thema Akku?

Ich habe mal nach Batterien / Akkus geschaut (sitze immer noch fest, daher habe ich Lagenw.... äähh ... ich meinte Zeit!) Ich finde diese flachen LiPos ziemlich praktisch. In der Größe 5x6cm gibt es z.B. diesen hier:

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

Müsste man eben rechtzeitig bestellen, dauert etwa 30 Tage, bis das Zeugs hier an kommt. Diesen Akku könnte man aber schön flach, doppelseitiges Klebeband oder Powerstrip, an das NOKOlino-Paket anbringen. Er ist nur 3,8mm dick!
Dieser Lieferant hat so ziemlich alle Größen und Formen, in meinen NOKOs tun dies Akkus ihren Dienst bis jetzt ohne Ausfälle.

vG
Crayfish

NikolaiRadke, 2018-01-19:
Ja, solche ähnlichen Akkus verwende ich ja in NOKO.
Ich habe mich für den etwas höheren entschieden, weil die schnell und reichlich für ähnlich kleines Geld verfügbar sind. Aber bei einer 5x6cm-Platine hat der geneigte Bastler ja dann mehr Wahlfreiheit :-)

Closed 2018-03-05.

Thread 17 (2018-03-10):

Fehler beim Bootloader frashen

AntoniusOD, 2018-03-10:
Mein Sohn und ich versuchen dein tolles Projekt nachzubauen. Heute haben wir damit angefangen und sind bis zum ersten flashen gekommen.
Wenn wir das Bootloader brennen auslösen, erhalten wir die Fehlermeldung:

avrdude: Device signature = 0x000000
avrdude: Yikes!  Invalid device signature.
         Double check connections and try again, or use -F to override
         this check.

Wir verwenden einen ELEGOO MEGA2560 R3 und einen attiny85-20 pu, die Verdrahtung habe ich mehrfach überprüft. Was können wir noch überprüfen?

NikolaiRadke, 2018-03-10:
0x000000 bedeutet, dass gar nix gefunden wurde, also die Verbindung nicht hinhaut. Kein Wunder, denn die Verkabelung für einen Mega ist anders:

Attiny -> Mega
Pin 1 -> Pin 53
Pin 2 -> leer
Pin 3 -> leer
Pin 4 -> GND

Pin 8 -> 5V
Pin 7 -> Pin 52
Pin 6 -> Pin 50
Pin 5 -> Pin 51

Den Elko nicht vergessen.
Viel Erfolg!

NikolaiRadke, 2018-03-10:
Gerne.
Der Elko verhindert, dass der Arduino automatisch einen Reset während des Beschreibens durchführt, der hardwareseitig ausgelöst wird. Er dient sozusagen als Puffer für das Signal.

NikolaiRadke, 2018-03-12:
Foto an mich nicht vergessen!
:-D

mettmaniac, 2018-03-12:
Nachdem ich hier grade Stunden mit einem RobotDyn MegaR3 verbracht habe und schon echt alles moegliche vermutet habe (defekte ATTiny85 von AliExpress geliefert bekommen? China-Verbindungskabel kaputt? Elko defekt?), wollte ich kurz darauf hinweisen, dass scheinbar bei einigen Mega-Clonen nicht Pin 53 sondern stattdessen Pin 10 zu verwenden ist. Damit hat es bei mir geklappt :)

Attiny -> Mega
Pin 1 -> Pin **10**
Pin 2 -> leer
Pin 3 -> leer
Pin 4 -> GND

Pin 8 -> 5V
Pin 7 -> Pin 52
Pin 6 -> Pin 50
Pin 5 -> Pin 51

NikolaiRadke, 2018-03-12:
Danke!
Ich werde die Belegung für den Mega in das Wiki aufnehmen, zusammen mit beim Hinweis auf Pin 10. Ich kann es mangels Arduino Mega nicht testen. Vielleicht habe ich mal einen, wenn ich groß und reich bin.

Fragen geklärt? Dann wird hier morgen geschlossen. Das ist wie ToDo-Listen abhaken :-)

mettmaniac, 2018-03-13:
9 USD bei AliExpress ;)

Von mir aus kann hier zugemacht werden.

NikolaiRadke, 2018-03-13:
Weiter gehts :-)

Closed 2018-03-13.

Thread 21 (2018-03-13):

JQ6500 Zugriffsfehler

AntoniusOD, 2018-03-13:
Ich hänge beim bespielen des JQ6500 fest. Ich verstehe es so, dass er einfach mit einem USB-Kabel an PC angeschlossen wird und man mit dem kleinen Tool, das auf dem JQ liegt, die MP3-Dateien drauf kopiert.

Bei mir wird der JQ zwar als CD-Laufwerk erkannt (PuP erkennt das Gerät und installiert die Treiber) , nur kann man nicht darauf zugreifen, es verhält sich wie ein CD Laufwerk ohne CD.

Ich habe mir das Update Tool aus dem Netz geholt, aber da erhalte ich auch nur einen "flashdata error".
Bisher habe ich es auf verschiedenen PC's  unter Win10 und Win7 mit verschiedenen USB Kabeln/Ports versucht. Letztlich habe ich einen neuen JQ6500-16p V2.1 gekauft - leider mit dem gleichen Resultat.

NikolaiRadke, 2018-03-13:
Oje - da hast Du keine Chance. Wenn dieses Tool nicht von Haus aus auf dem Modul ist, kann es (momentan) von Windows aus nicht beschrieben werden.

Bei manchen dieser chinesischen Qualitätsprodukte kommt das leider vor. Unter Linux geht es problemlos.

Wenn Du kein Linux hast, kann ich Dir nur anbieten, Dir ein bespieltes Modul per Post zu schicken.

AntoniusOD, 2018-03-13:
Linux habe ich nicht und ich kenne mich mit Linux auch nicht aus, daher würde ich dein Angebot gerne annehmen. Wo soll ich den JQ6500 hinschicken?

NikolaiRadke, 2018-03-13:
Ich habe eben meine fünf Module unter Windows getestet - keines davon hatte das Tool drauf. Gibt wohl Anbieter (ebay), die Ausschussware verkaufen. Ärgerlich.

Bitte eine Email an kontakt@nikolairadke.de

Closed 2018-03-13.

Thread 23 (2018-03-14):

JQ6500 mit 32MBit und Windows

NikolaiRadke, 2018-03-14:
Leider wird in den meisten Fällen das Modul ohne vorinstallierte Windows-Software ausgeliefert. Es ist nicht möglich, unter Windows die Dateien aufzuspielen, auch nicht, wenn die Software heruntergeladen und manuell gestartet wird, da sie sich auf dem virtuellen Laufwerk befinden muss.

Ich habe ein Mini-Linux (ca. 19 MB) erstellt, mit dem ein bootfähiger USB-Stick erstellt werden kann. Darauf befinden sich auch das Tool und die MP3s zum beschreiben des Moduls. Es funktioniert bereits, aber ich muss es noch für Neulinge komfortabler machen.

NikolaiRadke, 2018-03-15:
Offenbar betrifft das beinahe alle 32MBit-Modelle. Sie können nicht unter Windows bespielt werden. Mit dem Image, zu dem in Kürze (morgen?) die Anleitung folgt, ist es nun Möglich, eine angepasste Software auf das Modul zu schreiben und den Upload auch unter Windows vorzunehmen.

Abwarten, alles wird gut :-)

NikolaiRadke, 2018-03-16:
Fertig!

Ich habe ein neues Repository erstellt, in dem ein bootfähiges ISO-Image (20 MB!) bereitgestellt wird, das Module ohne Uploadsoftware repariert: [JQ6500_rescue_tool](https://github.com/NikolaiRadke/JQ6500-rescue-tool)

Perfekt für Windows-Nutzer ohne Lust, sich in Linux einzuarbeiten (was ich aber grundsätzlich empfehle... ;-) )

Viel Spaß!

ripe-banana, 2018-03-28:
Ich habe ein 16MBit Modell (JQ6500-16P v2.1). Dieses wurde auch ohne Windows-Oberfläche ausgeliefert.

- Erster Versuch (fehlgeschlagen): Linux tool von Reinhard Max hat Modul eigentlich erkannt, jedoch bei der Durchführung mit Fehler abgebrochen.
- Zweiter Versuch (fehlgschlagen): Rescue tool (Version vom 28.03.2018) hat Modul nicht erkannt.
- Dritter Versuch (erfolgreich): Auf [Gogo_Tronics](https://sparks.gogo.co.nz/jq6500/index.html) unter _"Or if you are really stuck you can download this zip file [...]"_ habe ich dieses File gefunden: [JQ6500_voice_chip_module.zip](https://sparks.gogo.co.nz/assets/_site_/downloads/JQ6500_voice_chip_module.zip). Die Ausführung in Windows per command line von mydown.bat hat schließlich die Windows-Oberfläche problemlos auf das Modul geflashed.

Kann man letztere Variante evtl. in das Wiki (Seite: "MP3s aufspielen") aufnehmen?

NikolaiRadke, 2018-04-06:
Hallo!

Sorry für die späte Antwort, habe ich glatt übersehen. Danke für den Hinweis!
Reinhard hat das Tool überarbeitet und ich werde das ISO neu anpassen.

Hast Du Windows 10? Ich habe mydown.bat da ums Verrecken nicht zum laufen bekommen, daher habe ich überhaupt das ISO erstellt. Ich werde es aber nochmal probieren. Bin ja jetzt ermutigt. Das Wiki wird natürlich entsprechend überarbeitet (Das wird eh mal wieder Zeit).

Liebe Grüße,

Nikolai

Closed 2018-03-17.

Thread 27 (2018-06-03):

cannot burn the bootloader to ATTiny

astaykov, 2018-06-03:
Hi,
we have purchased the NOKOLino at Maker Fair Berlin.
The issue is - we cannot burn the bootloader to the ATTiny.
We Use UNO Board, and all the wirings are made as shown.  The UNO board is working fine.
But when we try to burn the bootloader to AATiny45, which was in the package, we only get this errors:

avrdude: Version 6.3, compiled on Jan 17 2017 at 12:00:53
         Copyright (c) 2000-2005 Brian Dean, http://www.bdmicro.com/
         Copyright (c) 2007-2014 Joerg Wunsch

         System wide configuration file is "C:\Users\anstayk\AppData\Local\Arduino15\packages\arduino\tools\avrdude\6.3.0-arduino9/etc/avrdude.conf"

         Using Port                    : COM4
         Using Programmer              : stk500v1
         Overriding Baud Rate          : 19200
avrdude: Send: 0 [30]   [20]
avrdude: Send: 0 [30]   [20]
avrdude: Send: 0 [30]   [20]
avrdude: ser_recv(): programmer is not responding
avrdude: stk500_recv(): programmer is not responding
avrdude: stk500_getsync() attempt 1 of 10: not in sync: resp=0x03
avrdude: Send: 0 [30]   [20]
avrdude: ser_recv(): programmer is not responding
avrdude: stk500_recv(): programmer is not responding
avrdude: stk500_getsync() attempt 2 of 10: not in sync: resp=0x03
avrdude: Send: 0 [30]   [20]
avrdude: ser_recv(): programmer is not responding
avrdude: stk500_recv(): programmer is not responding
avrdude: stk500_getsync() attempt 3 of 10: not in sync: resp=0x03
avrdude: Send: 0 [30]   [20]
avrdude: ser_recv(): programmer is not responding
avrdude: stk500_recv(): programmer is not responding
avrdude: stk500_getsync() attempt 4 of 10: not in sync: resp=0x03
avrdude: Send: 0 [30]   [20]
avrdude: ser_recv(): programmer is not responding
avrdude: stk500_recv(): programmer is not responding
avrdude: stk500_getsync() attempt 5 of 10: not in sync: resp=0x03
avrdude: Send: 0 [30]   [20]
avrdude: ser_recv(): programmer is not responding
avrdude: stk500_recv(): programmer is not responding
avrdude: stk500_getsync() attempt 6 of 10: not in sync: resp=0x03
avrdude: Send: 0 [30]   [20]
avrdude: ser_recv(): programmer is not responding
avrdude: stk500_recv(): programmer is not responding
avrdude: stk500_getsync() attempt 7 of 10: not in sync: resp=0x03
avrdude: Send: 0 [30]   [20]
avrdude: ser_recv(): programmer is not responding
avrdude: stk500_recv(): programmer is not responding
avrdude: stk500_getsync() attempt 8 of 10: not in sync: resp=0x03
avrdude: Send: 0 [30]   [20]
avrdude: ser_recv(): programmer is not responding
avrdude: stk500_recv(): programmer is not responding
avrdude: stk500_getsync() attempt 9 of 10: not in sync: resp=0x03
avrdude: Send: 0 [30]   [20]
avrdude: ser_recv(): programmer is not responding
avrdude: stk500_recv(): programmer is not responding
avrdude: stk500_getsync() attempt 10 of 10: not in sync: resp=0x03

avrdude done.  Thank you.

Error while burning bootloader.

all the wiring between Arduino and ATTiny is double and triple checked (also with multimeter to confirm there is a connection)

astaykov, 2018-06-03:
Fixed it.
The IPS sketch was not successfully uploaded to the UNO

NikolaiRadke, 2018-06-03:
Well... i'm glad i could help ;-)
Have fun!

Closed 2018-06-03.

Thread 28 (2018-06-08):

NOKOlino im Dunkeln aus

hfried, 2018-06-08:
Ich möchte gerne den NOKOlino so ändern, dass er durch eine Fotodiode bzw. Fototransistor ein bzw. aus geschaltet werden kann und nicht (nur) durch einen Schalter. Die Idee ist,, das NOKOlino in seinen "Monstersack" (dunkler Sack) gesteckt wird, wenn er leise sein soll und auch Nachts automatisch ausgeschaltet ist.

Ist das möglich? Kann mir da jemand helfen?

NikolaiRadke, 2018-06-14:
Mit einem LDR (den hatte ich noch rumliegen) funktioniert es prinzipiell, ist aber nicht wirklich zufriedenstellend. Ich werde es nun mit einem Fototransistor versuchen, was aber mangels Fototransistor noch eine kurze Weile dauert.

Liebe Grüße,

Nikolai

hfried, 2018-06-14:
Hallo Nikolai,

danke für Deine ersten Versuche. Bei mir dauert es auch länger, da ich noch auf das MP§-Modul warte.

Gruß Horst

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

NikolaiRadke, 2018-06-28:
Gestern sind die Fototransistoren gekommen. Ich werde mich jetzt die Tage damit beschäftigen. Denke mal, das ist die richtige Lösung, da die Dinger, im Gegensatz zum LDR, Spannungsunabhängiger sind.

hfried, 2018-06-29:
Hört sich gut an, Bei mir sind die MP§-Module angekommen, ich werde den ersten Versuchsaufbau starten.

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

NikolaiRadke, 2018-06-29:
Hallo Horst,
ich habe heute ein paar Versuche mit einem SFH300-Fototransistor gemacht und mit einem 20kOhm Widerstand gute Ergebnisse bei Spannungen von 4,2 bis 3,3V erzielt.

Soll NOKOlino auch die Klappe halten, wenn der Bauch gedrückt wird?

Die Programmierung und den Aufbau habe ich soweit fertig, ich mache Dir einen Bauplan, wo die beiden Bauteile und eine Verbindung zum ATtiny am Pin 2 hin müssen.

hfried, 2018-06-29:
Super, ich bin der Ansicht, im Dunkeln soll er die Klappe halten.
Sind damit alle Pins belegt?

Gruß Horst

Von meinem Samsung Galaxy Smartphone gesendet.

NikolaiRadke, 2018-06-29:
Pin 5 (D0) ist noch frei.
Die Programmierung wäre fertig, liegt unter scr im GitHub als NOKOlino_lichtschalter.ino

Bilder kommen demnächst. Oder willst Du das alleine machen? Der Transistor kommt in Sperrichtung an den ATtiny, also Kollektor (kurzes Bein) zu VCC und Emitter (langes Bein) an Pin 2, dazu von dort ein 20k-Widerstand an GND.

hfried, 2018-06-30:
Super. Bilder wären sehr hilfreich

- Horst

Von meinem Samsung Galaxy Smartphone gesendet.

-------- Ursprüngliche Nachricht --------
Von: Nikolai Radke <notifications@github.com>
Datum: 29.06.18 21:29 (GMT+01:00)
An: NikolaiRadke/NOKOlino <NOKOlino@noreply.github.com>
Cc: "Friedrich, Horst" <horst.friedrich@fokus.fraunhofer.de>, Author <author@noreply.github.com>
Betreff: Re: [NikolaiRadke/NOKOlino] NOKOlino im Dunkeln aus (#28)

Pin 5 (D0) ist noch frei.
Die Programmierung wäre fertig, liegt unter scr im GitHub als NOKOlino_lichtschalter.ino

Bilder kommen demnächst. Oder willst Du das alleine machen? Der Transistor kommt in Sperrichtung an den ATtiny, also Kollektor (kurzes Bein) zu VCC und Emitter (langes Bein) an Pin 2, dazu von dort ein 20k-Widerstand an GND.

—
You are receiving this because you authored the thread.
Reply to this email directly, view it on GitHub<https://github.com/NikolaiRadke/NOKOlino/issues/28#issuecomment-401451792>, or mute the thread<https://github.com/notifications/unsubscribe-auth/AMXgqHsfWYDLdECms7MNUQ3VwtFmYuI4ks5uBoAFgaJpZM4UfmZ0>.

hfried, 2018-07-01:
Hallo Nikolai,

ich komme jetzt nicht weiter. Das größte Problem bis jetzt war, die 4MB MP3-Dateien auf en JQ6500 zu laden (Ich baue gleich zwei NOKOlinos zusammen, für meine Enkel). Weder USB-Stick noch gebrannte CD gingen auf alle meine drei WINDOWS Rechnern nicht. Ich habe das aber mit einem Ubuntu-Rechner eines Freundes geschafft. Ich habe nach einer ARDUINO Lösung gesucht, aber nichts gefunden.

Jetzt weiß ich nicht, was ist der Pin 2. Es gibt im Netz Nummerierungen der Pins, bei der ist Pin 2 neben Reset (Pin 1). Dann wird auch der Pin neben VCC als Pin 2 bezeichnet. Wenn man die Nummerierung von Analog Input wählt, dann ist Pin 2 neben Ground. Sorry, für diese einfache Frage, aber ich habe noch nicht mit dem ATtiny gearbeitet.

Gruß Horst

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

NikolaiRadke, 2018-07-03:
Hallo Horst,
das mit dem ISO nervt schon gewaltig. Das höre ich öfter, ich kann mir das leider nicht erklären, bei meinen Rechnern booten sie problemlos. Da muss ich wohl noch mal ran. Was passiert denn, wenn Du versuchst, davon zu booten?

Eine Arduino-Lösung existiert nicht, der Speicher des Moduls kann nur über USB beschrieben werden.

Die Pin- und Portbezeichnung sorgt regelmäßig für babylonische Sprachverwirrung :-) Ich meine in der Tat der Pin neben Reset. An diesem Pin liegen A3 und D3.

Anbei eine Grafik, wie der Fototransistor SFH300 und R1 mir 20kOhm eingebaut werden. So ganz zufrieden bin ich noch nicht, ich werde mich mal morgen mit einer Widerstandsdekade ransetzen und den optimalen Widerstand ermitteln.

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

hfried, 2018-07-04:
Hi Nikolai,

ich mache jetzt erstmal eine 3 wöchige Pause und bin am 23.07 wieder im Lande.

Was passiert beim booten? Auf zwei Rechnern sehe ich bei der Auswahl, von welchem Gerät gebootet werden soll, den USB-Stick bzw. das externe CD-Laufwerk (so interpretiere ich die Ausschrift). Wenn ich die auswähle, ist er sofort wieder in der Auswahlmaske.

Auf meinem „modernsten“ Windows-Rechner kommt die Information, dass der boot-Sektor der CD nicht verifiziert werden kann.

Hätte das mit dem Ubuntu-Rechner nicht geklappt, hätte ich es mit dem raspberry pi versucht. Damit müsste es doch gehen, nur dass man alles compilieren muss. Meine Vermutung ist, dass die NOKOLino-Nachbauer eher ein raspberry pi als ein UNIX-PC haben.

Danke für die Zeichnung. Wenn ich das richtig verstehe, bildet Fototransistor und der Widerstand einen Spannungsteiler und diese „geteilte“ Spannung wird von PIN 2 abgefragt. Welche Spannung sollte an PIN 2 anliegen, wenn es hell ist und wenn es dunkel wird? Mit der Info könnte ich auch experimentieren, da ich zwei Fototransistoren von den Mini-Roboter Kabibo habe, die ich erstmal verwenden wollte.

Gruß Horst

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

NikolaiRadke, 2018-07-05:
Lieber Horst,

vielleicht liegt es an BIOS/UEFI. Ich dachte, meine Version kann beides. Probiere doch mal bitte, im BIOS entsprechen umzuschalten.

Ich habe mit einer Widerstandsdekade rumgespielt und bei einem 4k-Widerstand den besten Wert erhalten. An A3 soll 0 anliegen. Der Wert kann man der bedeutungsvollen Konstante "Darkness" angepasst werden, um die Toleranzschwelle zu heben, von 0 bis 1023. Du kannst ja mit einem Multimeter die Spannung am Pin messen. Entspricht der Wert der Versorgungsspannung ist es hell und müsste einen Wert >900 haben.

NikolaiRadke, 2018-07-07:
Ich habe ein wenig mit meiner Widerstandsdekade rumgespielt: 220k brachte das beste Ergebnis, dann muss es schon ziemlich dunkel im Zimmer sein. Das gilt natürlich nur für den SFH300.

Demnächst füge ich das Bild und eine Anleitung zum Wiki hinzu, also optionales Feature.

NikolaiRadke, 2018-09-07:
Hallo Horst,

Die PCB-Version von NOKOlino, [NOKOlino_2](https://github.com/NikolaiRadke/NOKOlino_2) hat jetzt diese Funktion optional mit an Board bzw. auf dem Bord und wird gerade ins dortige Wiki aufgenommen. Das Wiki des Ur-NOKOlino folgt danach.

Liebe Grüße,

Nikolai

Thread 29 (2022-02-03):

Attiny85/Digispark Support?

dnmtch, 2022-02-03:
Hi
(not a bug, feel free to close without notice)

I wanted to recreate a Nokilino with a Attiny85/Digispark. Unfortunately, I fail because of the used Libraries (EEPROM.h and SoftwareSerial.h). Am I doing something wrong or would the code have to be adapted for this?
(DigisparkSoftSerial does not work for me)

NikolaiRadke, 2022-02-03:
Hi!

I will have a look soon.

NikolaiRadke, 2022-02-04:
Hello again,

i made a Digispark version:
* SoftwareSerial.h is called SortSerial.h.
* EEPROM.h is working but not included in the Digispark package, i don't now why... Now it is included in the src/ folder.
* analogRead(A2) is now analogRead(2)
* Alas, battery warning is not working, Attiny is not good implemented in the package.

Hopefully it is working, i can't test it by myself, i don't have a Digispark module. Be sure to set the clock to 8 MHz or JQ6500 may have problems.

Good luck!

dnmtch, 2022-02-05:
Thank you very much. I have here a "screaming" JQ8400-FL-10P which is connected to a Digispark. (Power via USB, all "eeprom_write_word" code commented out).

The code for the JQ6500 compiles correctly. The code for the JQ8400 unfortunately not.

Code: https://github.com/NikolaiRadke/Nokolino_pcb/tree/master/src/Nokolino_V31
Error:
```
C:\~\Nokolino_Digispark2.ino.ino: In function 'int main()':
Nokolino_Digispark2.ino:125:34: error: invalid conversion from 'uint16_t {aka unsigned int}' to 'uint16_t* {aka unsigned int*}' [-fpermissive]
       eeprom_write_word(address,0);    // Write seed 0
                                  ^
In file included from C:\~\libraries\EEPROM/EEPROM.h:25:0,
                 from C:\~\Nokolino_Digispark2.ino\Nokolino_Digispark2.ino.ino:26:
c:\~\appdata\local\arduino15\packages\arduino\tools\avr-gcc\4.8.1-arduino5\avr\include\avr\eeprom.h:689:6: error:   initializing argument 1 of 'void __eewr_word_tn85(uint16_t*, uint16_t)' [-fpermissive]
 void eeprom_write_word (uint16_t *__p, uint16_t __value);
      ^
Nokolino_Digispark2.ino:127:34: error: invalid conversion from 'uint16_t {aka unsigned int}' to 'const uint16_t* {aka const unsigned int*}' [-fpermissive]
     seed=eeprom_read_word(address);    // Read seed
                                  ^
In file included from C:\~\Arduino\libraries\EEPROM/EEPROM.h:25:0,
                 from C:\~\Arduino\Nokolino V2.1 Digispark\Nokolino_Digispark\Nokolino_Digispark2.ino\Nokolino_Digispark2.ino.ino:26:
c:\~\arduino15\packages\arduino\tools\avr-gcc\4.8.1-arduino5\avr\include\avr\eeprom.h:662:10: error:   initializing argument 1 of 'uint16_t __eerd_word_tn85(const uint16_t*)' [-fpermissive]
 uint16_t eeprom_read_word (const uint16_t *__p) __ATTR_PURE__;
          ^
Nokolino_Digispark2.ino:135:35: error: invalid conversion from 'uint16_t {aka unsigned int}' to 'uint16_t* {aka unsigned int*}' [-fpermissive]
     eeprom_write_word(address,seed);   // Save new seed for next startup
                                   ^
In file included from C:\~\Arduino\libraries\EEPROM/EEPROM.h:25:0,
                 from C:\~\Arduino\Nokolino V2.1 Digispark\Nokolino_Digispark\Nokolino_Digispark2.ino\Nokolino_Digispark2.ino.ino:26:
c:\~\arduino15\packages\arduino\tools\avr-gcc\4.8.1-arduino5\avr\include\avr\eeprom.h:689:6: error:   initializing argument 1 of 'void __eewr_word_tn85(uint16_t*, uint16_t)' [-fpermissive]
 void eeprom_write_word (uint16_t *__p, uint16_t __value);
      ^
Multiple libraries were found for "SoftSerial.h"
 Used: C:\~\Arduino\libraries\DigisparkSoftSerial
 Not used: C:\~\Arduino15\packages\digistump\hardware\avr\1.6.7\libraries\DigisparkSoftSerial
Multiple libraries were found for "TinyPinChange.h"
 Used: C:\~\libraries\DigisparkTinyPinChange
 Not used: C:\~\Arduino15\packages\digistump\hardware\avr\1.6.7\libraries\DigisparkTinyPinChange
exit status 1
invalid conversion from 'uint16_t {aka unsigned int}' to 'uint16_t* {aka unsigned int*}' [-fpermissive]
```

NikolaiRadke, 2022-02-05:
I added a JQ8400 version here:
[https://github.com/NikolaiRadke/Nokolino_pcb/tree/master/src](https://github.com/NikolaiRadke/Nokolino_pcb/tree/master/src)

Can you guess the time interval between the random talking? Maybe you should flash the bootloader to set the Attiny85 to  8 MHz.

dnmtch, 2022-02-05:
The time intervals are mostly correct. The chip programmed with the correct settings (8mhz no USB). But the button does not work correctly. At most, no pressing is detected.

NikolaiRadke, 2022-02-07:
I see. the hardware close programming to save flash space may cause problems with the digispark package. Now the button is questioned by standard Arduino code. Give it a try.

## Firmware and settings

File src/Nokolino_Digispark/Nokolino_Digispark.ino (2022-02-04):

/* Nokolino V2.1 03.08.2019 - Nikolai Radke
 *  
 *  Sketch for Mini-Noko-Monster
 *  for Attiny45/85 | 8 Mhz - remember to flash your bootloader first!
 *  SoftwareSerial needs 8 MHz to work correctly.
 *  
 *  Flash-Usage: 3.696 (1.8.12 | ATTiny 1.0.2 | Linux X86_64 | ATtiny85)
 *  
 *  Circuit:
 *  1: RST | PB5  free
 *  2: A3  | PB3  Optional SFH300          
 *  3: A2  | PB4  Busy JQ6500 - 8
 *  4: GND        GND
 *  5: D0  | PB0  free
 *  6: D1  | PB1  RX JQ6500   - 9   
 *  7: D2  | PB2  Button      - GND
 *  8: VCC        VCC
 *  
 *  Sleepmodes:
 *  0=16ms, 1=32ms, 2=64ms, 3=128ms, 4=250ms, 5=500ms
 *  6=1sec, 7=2sec, 8=4sec, 9=8sec
 */

#include <avr/sleep.h>
#include <avr/interrupt.h>
#include <SoftSerial.h>
#include <EEPROM.h>

//--------------------------------------------------------------------------------
// Configuation
#define Time         10             // Say something every statistical 10 minutes
#define Volume       25             // Volume 0-30 - 25 is recommended 
#define Darkness     4              // Optional: The lower the darker the light must be

//#define Breadboard                // Breadboard or PCB?

// Voice set selection
#define Set_16MBit
//#define Set_32MBit
//#define Set_own

#ifdef Set_16MBit
  #define Button_event 30           // Last button event number (30.mp3)
  #define Time_event   79           // Last time event number (79.mp3)
#endif
#ifdef Set_32MBit
  #define Button_event 40
  #define Time_event   163
#endif
#ifdef Set_own
  #define Button_event 0
  #define Time_event   0
#endif

#ifdef Breadboard
  #define Offset       0.3          // Battery measuring error
  #define maxInput     50           // Max. value from busy line. 
#else
  #define Offset       0.1
  #define maxInput     0
#endif

// Optional - comment out with // to disable
//#define Lightsensor               // Nokolino will be quite in the dark
#define StartupBeep                 // Nokolino will say "beep" when turned on

//---------------------------------------------------------------------------------

// Optional battery warning
#define minCurrent   3.60 +Offset  // Low power warning current + measuring error
#define battLow      3.50 +Offset  // Minimal voltage before JQ6500 fails

// Hardware pins
#define TX      0
#define RX      1
#define Busy    2

// ADC and BOD
#ifndef cbi
  #define cbi(sfr, bit) (_SFR_BYTE(sfr) &= ~_BV(bit))
#endif
#ifndef sbi
  #define sbi(sfr, bit) (_SFR_BYTE(sfr) |= _BV(bit))
#endif
#define BODS 7                         // BOD sleep bit in MCUCR
#define BODSE 2                        // BOD sleep enable bit in MCUCR

// Variables
uint16_t eeprom,seed;
uint16_t *address;
volatile boolean f_wdt = 1;            // Volatile -> it is an interrupt routine
boolean low=false;
boolean dark=false;

SoftSerial mp3(TX,RX);                 // TX to D0, RX to D1

int main(void) {

#ifdef Batterywarning
  uint16_t current;
  double vref;
  uint16_t counter=10;                 // Check shortly after startup
#endif

init(); {
  // Power saving
  MCUCR |= _BV(BODS) | _BV(BODSE);     // Disable brown out detection - default?
  ACSR |= _BV(ACD);                    // Disable analog comparator - default?
  DDRB &= ~(1<<PB2);                   // D2 INPUT
  PORTB |= (1<<PB2);                   // D2 HIGH 

  // Loop if there is a USB data connection for upload
  setup_watchdog(6);                   // Set sleep time to 1000ms  
  if (!(PINB & (1<<PB2))) {            // If button is pressed during startup
    while(1) attiny_sleep();           // sleep forever to upload files to JQ6500
  }
  
  // Start JQ6500
  mp3.begin(9600);
  mp3.write("\x7E\x02\x0C\xEF");       // Reset JQ6500
  setup_watchdog(5);                   // Set sleep time to 500ms
  attiny_sleep();                      // Sleep 500ms
  mp3.write("\x7E\x03\x11\x04\xEF");   // No loop
  attiny_sleep();                      // Sleep 500ms

  address=&eeprom;
  // Randomize number generator
  *address=eeprom_read_word(0);         // Read EEPROM address
  if ((*address<2) || (*address>(EEPROM.length()-3))) {
  // Initialize EEPROM and size for first use or after end of cycle
    *address=2 ;                       // Starting address
    eeprom_write_word(0,*address);      // Write starting address
    eeprom_write_word(address,0);      // Write seed 0
  }
  seed=eeprom_read_word(address);     // Read seed
  if (seed>900) {                      // After 900 write-cyles move to another address                                   
    seed=0;                            // to keep the EEPROM alive
    *address+=2;
    eeprom_write_word(0,*address);
  }
  randomSeed(seed);                    // Randomize
  seed++;                              // New seed
  eeprom_write_word(address,seed);     // Save new seed for next startup

  // Optional startup beep
  #ifdef StartupBeep
    attiny_sleep();
    JQ6500_play(Time_event+1);         // Nokolino says "Beep"
  #endif

  mp3.write("\x7E\x02\x0A\xEF");       // Sleep, JQ6500!
  setup_watchdog(3);                   // Set sleep time to 128ms   
}

// Main loop
while(1)
{
  // Wait for button or time and go to sleep - ~8 times/second         
  if (!low && !dark) { // Quiet if battery too low or optional light too dark
    if (!(PINB & (1<<PB2))) JQ6500_play(random(0,Button_event+1));      // Button event
    else if (random(0,Time*60*8)==1) JQ6500_play(random(Button_event+1,Time_event+1)); // Time event
  }
  attiny_sleep();                      // Safe battery
  
  // Optional: Check darkness
  #ifdef Lightsensor
    if (analogRead(A3)<=Darkness) dark=true;
    else dark=false;
  #endif
}}

void JQ6500_play(uint8_t f) {          // Plays MP3 number f
  mp3.write("\x7E\x03\x06");
  mp3.write(Volume);                   // Set volume
  mp3.write("\xEF");                   // JQ6500 looses volume settings after sleep... 
  attiny_sleep();
  attiny_sleep();                      // Without long pause, pull-up messes the busy signal
  mp3.write("\x7E\x04\x03\x01");       // Play file number f
  mp3.write(f);
  mp3.write("\xEF");
  attiny_sleep();
  while (analogRead(2)>maxInput) attiny_sleep(); // Check busy
  mp3.write("\x7E\x02\x0A\xEF");       // Go back to sleep, JQ6500!
  attiny_sleep();
}

void attiny_sleep() {                  // Sleep to save power
  cbi(ADCSRA,ADEN);                    // Switch ADC off
  set_sleep_mode(SLEEP_MODE_PWR_DOWN); 
  sleep_mode();                                         
  sbi(ADCSRA,ADEN);                    // Switch ADC on
}

void setup_watchdog(uint8_t mode) {    // Setup wake time
  uint8_t bb;
  bb=mode & 7;
  if (mode > 7) bb|= (1<<5);
  bb|= (1<<WDCE);
  MCUSR &= ~(1<<WDRF);
  WDTCR |= (1<<WDCE) | (1<<WDE);
  WDTCR = bb;
  WDTCR |= _BV(WDIE);
}

ISR(WDT_vect) {                       // Set global flag
  f_wdt=1; 
}

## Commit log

2017-02-15 Added schematic
    [NOKOlino.sch]
2017-03-28 Updated schematics
    [NOKOlino.sch]
2017-03-31 Slightly improved power save mode
2017-04-02 NOKOlino now supports permanent pressed button
2017-12-31 Some cosmetical fixes
    [NOKOlino.sch]
2018-01-08 Update NOKOlino.ino
    Prevents problems when increasing button events
2018-01-15 Started kicad pcb design
    [NOKOlino.kicad_pcb, NOKOlino.sch]
2018-01-15 kicad - circuit done
2018-01-15 kicad - circuit done 2
2018-01-15 kicad - first PCB draft done
    [NOKOlino.dsn, NOKOlino.kicad_pcb, NOKOlino.sch]
2018-01-15 kicad - added first Gerber files and circuit PDF
    [NOKOlino-B.Cu.gbr, NOKOlino-B.Mask.gbr, NOKOlino-B.Paste.gbr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]
2018-01-15 kicad - added correct JQ6500 footprint
    [NOKOlino.kicad_pcb]
2018-01-15 kicad - almost finished PCB, added 3D image
    [NOKOlino-B.Cu.gbr, NOKOlino-B.Mask.gbr, NOKOlino-B.Paste.gbr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]
2018-01-16 kicad - 50x50mm Version, bitte Schaltplan (Ausgabe.pdf) überprüfen
    [NOKOlino-B.Cu.gbr, NOKOlino-B.Mask.gbr, NOKOlino-B.Paste.gbr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]
2018-01-16 kicad - slight changes in JQ6500 part, added NOKO Logo
    [NOKOlino.kicad_pcb]
2018-01-16 kicad - created new Gerber files
    [NOKOlino-B.Cu.gbr, NOKOlino-B.Mask.gbr, NOKOlino-B.Paste.gbr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]
2018-01-16 rotated logo
    [NOKOlino-B.Cu.gbr, NOKOlino-B.Mask.gbr, NOKOlino-B.Paste.gbr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]
2018-01-18 Lautsprecherfootprint und JST EH gewinkelte Stecker
    [NOKOlino-B.Cu.gbr, NOKOlino-B.Mask.gbr, NOKOlino-B.Paste.gbr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]
2018-01-20 Neueste Updates für die Diskussion in #6
    - MP3 Modul nach unten verschoben, so das möglichst viel Platz für einen
    USB Stecker ist
    - Befestigungslöcher des Lautsprechers entfernt
    - Die schematics/kicad/PDF/NOKOlino_PCB.pdf Datei ist ein
    (maßstabsgerechter?) Ausdruck der Leiterplatte, zum Ausprobieren der
    Größenverhältnisse, bitte mal testen, ob das alles so passt.
    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
    [NOKOlino-B.Cu.gbr, NOKOlino-B.Mask.gbr, NOKOlino-B.Paste.gbr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]
2018-01-21 NOKOlino logo added to library and board
    [NOKOlino.kicad_pcb]
2018-01-21 Neues PCB für die obere Platte
    - neues PCB angelegt (im Verzeichnis schematics/kicad_top_pcb. Dort sind
    Löcher zur Befestigung des Lautsprechers und Aussparungen für den
    Schallaustritt vorgesehen. Die Schlitze sind 1mm breit und haben 0,6mm
    Abstand - gibt es dagegen Einwände? Oder bessere Ideen?
    - Wegen besserer Stabilität mit Kupferflächen auf beiden Seiten
    - NOKOlino Logo kommt noch rauf
    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
    [kicad_top_pcb.kicad_pcb, kicad_top_pcb.sch]
2018-01-27 breitere Schlitze und Stege
    [kicad_top_pcb.kicad_pcb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]
2018-01-28 last changes, directories cleaned up
    [NOKOlino.kicad_pcb]
2018-01-28 added logo, created new 3D renders
    [kicad_top_pcb.kicad_pcb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]
2018-01-28 last changes, added fake pads to top PCB for drill file generation
    [kicad_top_pcb-B.Cu.gbr, kicad_top_pcb-B.Mask.gbr, kicad_top_pcb-B.Paste.gbr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]
2018-01-28 last changes
    [kicad_top_pcb-B.Cu.gbr, kicad_top_pcb-B.Mask.gbr, kicad_top_pcb-B.Paste.gbr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]
2018-01-28 noch mehr last changes
    [kicad_top_pcb.kicad_pcb]
2018-01-30 some file and directory structure cleanup and more pictures
    [NOKOlino.kicad_pcb, kicad_top_pcb.kicad_pcb]
2018-02-16 Fooprint of MP3 module corrected
    [NOKOlino.dsn, NOKOlino.kicad_pcb]
2018-02-16 Ever so slight correction footprint of TP module
    [NOKOlino.dsn, NOKOlino.kicad_pcb]
2018-02-18 removed ref*** labels
    [kicad_top_pcb.kicad_pcb]
2018-02-19 Create Gerber files
    [NOKOlino-B.Cu.gbr, NOKOlino-B.Mask.gbr, NOKOlino-B.Paste.gbr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]
2018-03-12 Lautsprecher Zeichnung auf die Unterseite gerückt, nur die Oberseite hat jetzt das Logo und den Namen, ref*** ist beseitigt
    [kicad_top_pcb-B.Cu.gbr, kicad_top_pcb-B.Mask.gbr, kicad_top_pcb-B.Paste.gbr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]
2018-03-12 Gerber Zip File geupdated
2018-03-13 Akku Anschluss nach links gerückt
    [NOKOlino-B.Cu.gbr, NOKOlino-B.Mask.gbr, NOKOlino-B.Paste.gbr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]
2018-03-13 USB und Schalter zusammen, Akku Label zurecht gerückt
    [NOKOlino-B.Cu.gbr, NOKOlino-B.Mask.gbr, NOKOlino-B.Paste.gbr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]
2018-03-16 Schon wieder letzte Änderungen
    [NOKOlino-B.Cu.gbr, NOKOlino-B.Mask.gbr, NOKOlino-B.Paste.gbr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]
2018-05-01 Beschriftung der Anschlüsse berichtigt
    [NOKOlino.dsn, NOKOlino.kicad_pcb, NOKOlino.sch]
2018-05-01 GERBER files erstellt und ZIP geupdated
    [NOKOlino-B.Cu.gbr, NOKOlino-B.Mask.gbr, NOKOlino-B.Paste.gbr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]
2018-05-03 Enlarged solder pads
    [NOKOlino.dsn, NOKOlino.kicad_pcb]
2018-05-03 GERBER files created and ZIP archive updated
    [NOKOlino-B.Cu.gbr, NOKOlino-B.Mask.gbr, NOKOlino-B.Paste.gbr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]
2018-05-03 Init again
    [NOKOlino-B.Cu.gbr, NOKOlino-B.Mask.gbr, NOKOlino-B.Paste.gbr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]
2018-05-03 New gerber files
    [NOKOlino-B.Cu.gbr, NOKOlino-B.Mask.gbr, NOKOlino-B.Paste.gbr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]
2018-06-29 Improved power saving when battery is low
2020-06-03 Updated repository
    [Nokolino.sch]
